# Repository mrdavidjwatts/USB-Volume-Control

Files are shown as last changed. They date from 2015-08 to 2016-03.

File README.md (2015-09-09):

#USB-Volume-Control

Control Volume in your computer using this board! It takes advantage of the NicoHood HID library and core, make sure you have it installed in your Arduino IDE before running the code supplied - https://github.com/NicoHood/HID/wiki

##BOM

###Microcontroller

* Atmega32u4-AU

###Resistors:

* 2x 22 Ω 0805
* 300Ω 0805
* 10KΩ 0805

###Capacitors

* 0,1uF 0805
* 1uF 0805
* 10uF 0805
* 100uF 0805
* 22pF THT

###LEDs

* 2 x LED 1206 SMD
* LED THT 5mm

###Other

* USB Mini type B
* Rotary Encoder
* Crystal HC49S 16MHz
* 1x06 Header 2.54 mm or 0.1 in pitch

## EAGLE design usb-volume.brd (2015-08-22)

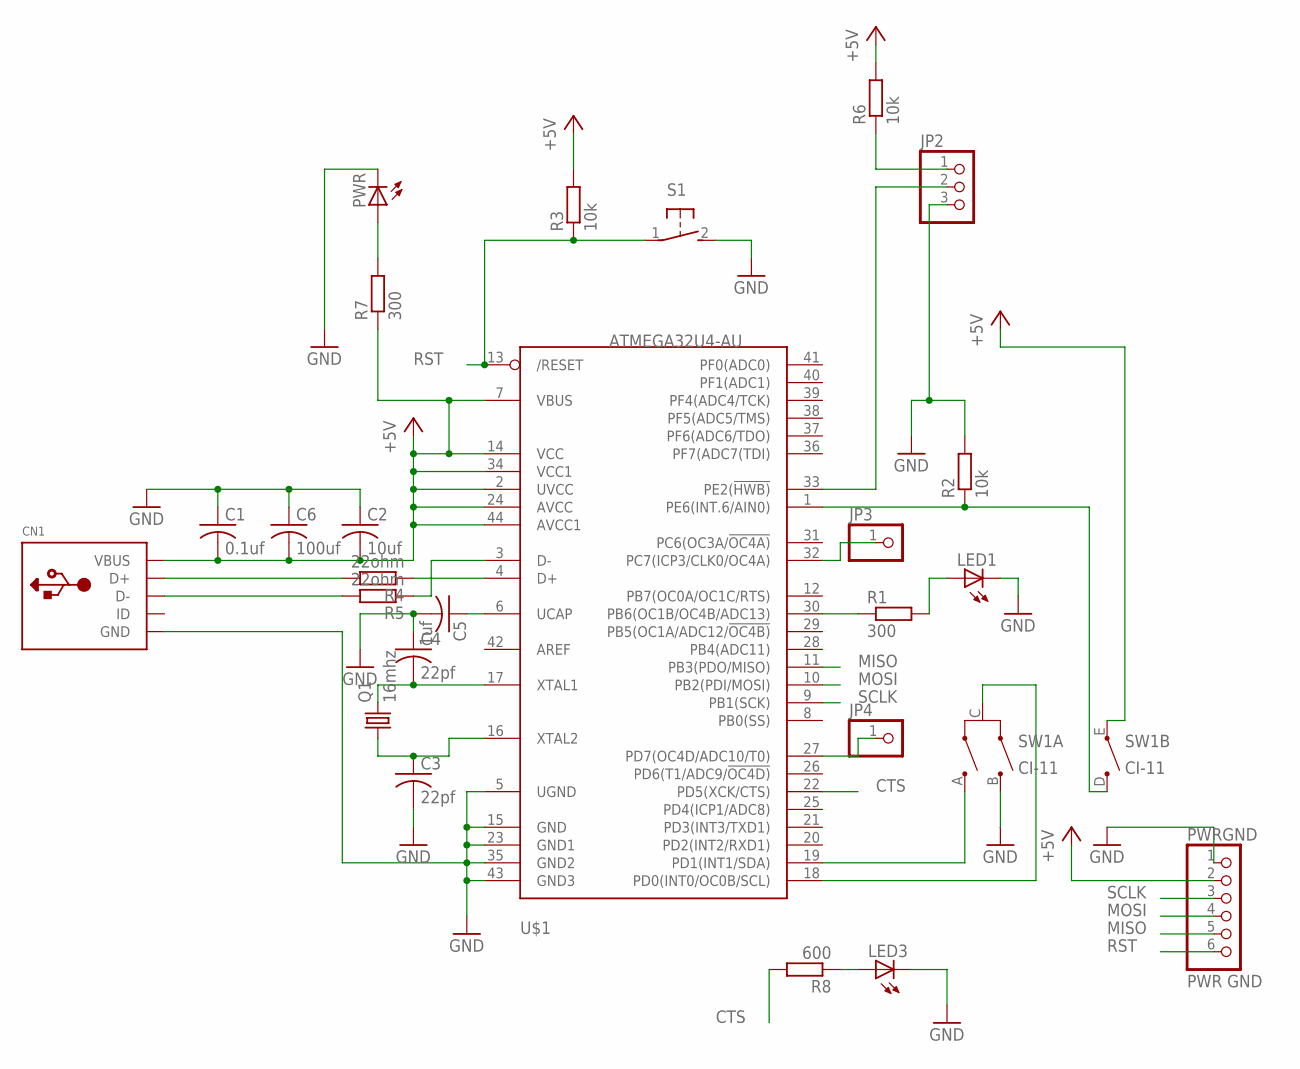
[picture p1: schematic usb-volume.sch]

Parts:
C1: 0.1uf; C0805
C2: 10uf; C0805
C3, C4: 22pf; C025-025X050
C5: 1uf; C0805
C6: 100uf; C0805
CN1: USBMINIB; USB-MINIB
JP2: PINHD-1X3; 1X03
JP3, JP4: PINHD-1X1; 1X01
LED1: LED5MM
LED3: LEDCHIPLED_1206; CHIPLED_1206
PWR: LEDCHIPLED_1206; CHIPLED_1206
PWRGND: PWR GND; 1X06
Q1: 16mhz; HC49/S
R1, R7: 300; R0805
R2, R3, R6: 10k; R0805
R4, R5: 22ohm; R0805
R8: 600; R0805
S1: 31-XX; B3F-31XX
SW1: CI-11
U$1: ATMEGA32U4-AU; TQFP44

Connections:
+5V: C1.2, C2.2, C6.2, CN1.VBUS, PWRGND.2, R3.2, R6.2, R7.1, SW1.E, U$1.2 (UVCC), U$1.7 (VBUS), U$1.14 (VCC), U$1.24 (AVCC), U$1.34 (VCC1), U$1.44 (AVCC1)
CTS: R8.2, U$1.22 (PD5(XCK/CTS))
GND: C1.1, C2.1, C3.2, C4.1, C5.2, C6.1, CN1.GND, JP2.3, LED1.K (C), LED3.C, PWR.C, PWRGND.1, R2.2, S1.2 (S), SW1.B, U$1.5 (UGND), U$1.15 (GND), U$1.23 (GND1), U$1.35 (GND2), U$1.43 (GND3)
MISO: PWRGND.5, U$1.11 (PB3(PDO/MISO))
MOSI: PWRGND.4, U$1.10 (PB2(PDI/MOSI))
unnamed: SW1.C, U$1.18 (PD0(INT0/OC0B/SCL))
unnamed: SW1.A, U$1.19 (PD1(INT1/SDA))
unnamed: C4.2, Q1.2, U$1.17 (XTAL1)
unnamed: R2.1, SW1.D, U$1.1 (PE6(INT.6/AIN0))
unnamed: C3.1, Q1.1, U$1.16 (XTAL2)
unnamed: CN1.D+, R4.2
unnamed: R5.1, U$1.3 (D-)
unnamed: R1.1, U$1.30 (PB6(OC1B/OC4B/ADC13))
unnamed: LED1.A, R1.2
unnamed: CN1.D-, R5.2
unnamed: R4.1, U$1.4 (D+)
unnamed: JP2.2, U$1.33 (PE2(!HWB))
unnamed: C5.1, U$1.6 (UCAP)
unnamed: JP2.1, R6.1
unnamed: PWR.A, R7.2
unnamed: JP3.1, U$1.32 (PC7(ICP3/CLK0/OC4A))
unnamed: LED3.A, R8.1
unnamed: JP4.1, U$1.27 (PD7(OC4D/ADC10/T0))
RST: PWRGND.6, R3.1, S1.1, U$1.13 (/RESET)
SCLK: PWRGND.3, U$1.9 (PB1(SCK))

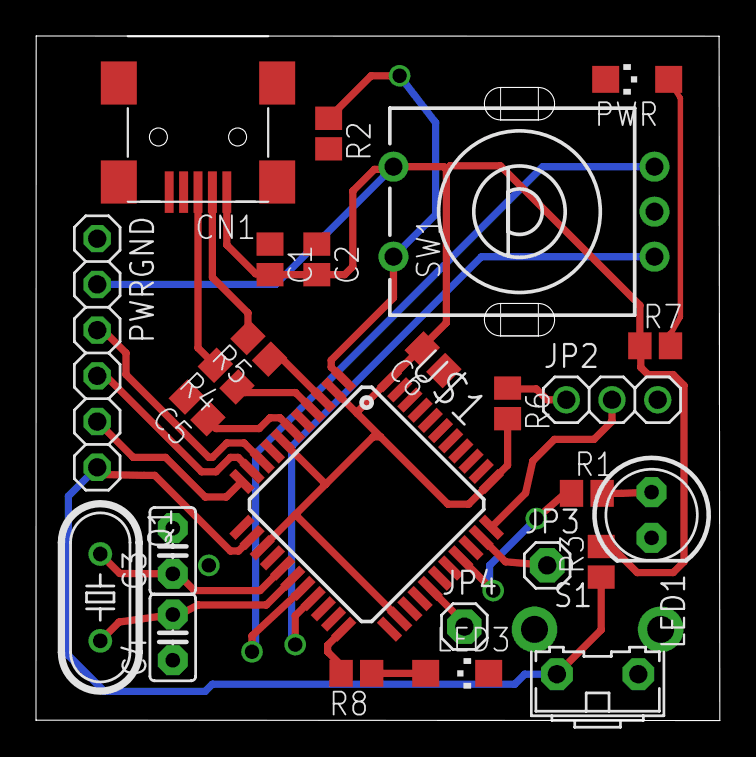
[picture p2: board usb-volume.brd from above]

Board: 2 copper layers, 38.0 x 38.0 mm, 26 parts (0 on the bottom side), 25 nets.

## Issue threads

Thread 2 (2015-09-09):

Consumer was not declared in this scope

LuisDiazUgena, 2015-09-09:
Hi!

I've been working on the code, make it easier to other users to read it. Also, i've added long click support, but when trying to verify the code, arduino says "Consumer was not declared in this scope".

I've tried to with Micro and Leonardo. Is there any library for Consumer objects? What am I missing?

Cheers!

mrdavidjwatts, 2015-09-09:
Hi,

I didn't specifically state it on Github, just in the youtube video I made about it. I use the NicoHood HID library and core, it avoids the need to write your own consumer USB HID descriptor. I have added a link and description into the readme.

LuisDiazUgena, 2015-09-09:
Great! It was driving me mad!

LuisDiazUgena, 2015-09-09:
Hi! I've downloaded HID library, but it still says that consumer was not declared. I don't know what to do, but I think that I'm going to switch to pjrc keyboard library.

mrdavidjwatts, 2015-09-09:
Did you install the hardware folder? You will need to select the Hoodloader
board type within the IDE in order for it to be able to use the consumer
USB HID descriptor.

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

mrdavidjwatts, 2015-09-09:
Instructions for setup should be on the Wiki page, I was up and running in a few minutes after selecting the right board from the boards menu. You can even install the boards from the boards manager.

LuisDiazUgena, 2015-09-09:
I've not been able to use it. I have not been able to install HID core, so I will try in a couple of days.

Thanks anyway :D

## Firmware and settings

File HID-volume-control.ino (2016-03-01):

#include <Encoder.h>
#include "HID-Project.h"
Encoder myEnc(3,2);
const int pinLed = LED_BUILTIN;
const int pinButton = 12;
int bulbPin = 10;
int oldPosition  = -999;
boolean muted = 0;
int safePosition = 0;
int volume = 0;
int oldVolume = 0;
int actualVolume = 0;

int intervale = 1000;
bool clicked = false;
int userDelay=250; //delay for debouncing

bool debug = false; //set to true to view messages on serial monitor
void setup() {

  pinMode(pinLed, OUTPUT);
  pinMode(2, INPUT_PULLUP);
  pinMode(3, INPUT_PULLUP);
  pinMode(8, INPUT_PULLUP);
  pinMode(pinButton, INPUT_PULLUP);

  Serial.begin(9600);
  delay(1000);

  Consumer.begin();

  for(int i = 50; i > 0; i--){
    Consumer.write(MEDIA_VOLUME_DOWN);
    delay(1);
  }
}

void loop() {

  //Encoder rotation
  int newPosition = myEnc.read();
  if (newPosition != oldPosition) {
    safePosition = newPosition;
    if(newPosition < 0){
      safePosition = 0;
      myEnc.write(safePosition);
    }
    if(newPosition > 400){
      safePosition = 400;
      myEnc.write(safePosition);
    }
    oldPosition = safePosition;
    volume = safePosition / 4;
    volume = volume / 2;
    noInterrupts();

    if (debug){
      Serial.print("calc volume: ");
      Serial.print(volume);
      Serial.print(" act volume: ");
      Serial.print(actualVolume);
      Serial.println("");
      Serial.println(map(volume, 0, 50, 0, 255));
    }
    
    changeVolume();
    interrupts();

  }

  //long && short click support
  unsigned long nextTime = millis();
  while(digitalRead(7)){
    clicked = true;
  }
  if(clicked){
    //The button has been clicked
    if(nextTime > millis() + intervale){
      //long click

    }else{
      //short click
      Consumer.write(MEDIA_VOLUME_MUTE);
      muted = !muted;
      delay(300);
    }
    delay(userDelay);
  }
  clicked=false;

  //Change led bright
  if(muted){
    analogWrite(bulbPin, 0);
  }
  else{
    analogWrite(bulbPin, map(volume, 0, 50, 0, 255));
  }

//  if (digitalRead(7)) {

//    Keyboard.press(KEY_LEFT_GUI);
 //   Keyboard.press('d');
 //   Keyboard.releaseAll();
 //   delay(300);
//  }
 //if (!digitalRead(8)) {
 // Keyboard.println("Thanks,");
  //Keyboard.println("");
  //Keyboard.println("David Watts");
   // Keyboard.println("Resident Nerd and Tinkerer");
  //  delay(300);
 // }

}

void changeVolume(){
  if (volume != oldVolume) {
      if(volume > oldVolume){
        //delay(100);
        Consumer.write(MEDIA_VOLUME_UP);
        actualVolume = actualVolume + 2;
        oldVolume = volume;
      }
      else{
        //delay(100);
        Consumer.write(MEDIA_VOLUME_DOWN);
        actualVolume = actualVolume - 2;
        oldVolume = volume;
      }
    }
}

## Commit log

2015-08-22 USB Volume Control with an ATMEGA32U4
    This is a USB HID volume control for PCs and Macs
    [usb-volume.brd, usb-volume.sch]
2015-08-22 updated schematics with values
    [usb-volume.brd, usb-volume.sch]
2015-09-08 Added BOM
2015-09-09 Added long/short click support, debug info and minor changes
    [HID-volume-control.ino]
